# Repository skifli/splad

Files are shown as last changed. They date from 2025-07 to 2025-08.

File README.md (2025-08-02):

# Splad

- [Splad](#splad)
  - [Project Structure](#project-structure)
  - [Journal](#journal)
  - [PCB](#pcb)
    - [Schematic](#schematic)
    - [PCB Design \[Left\]](#pcb-design-left)
    - [PCB Design \[Right\]](#pcb-design-right)
  - [BOM](#bom)
  - [Software](#software)

| Cover | Exploded View (ish) |
| --- | --- |
| cover photo | exploded view photo |

A 48 key split ergonomic keyboard, with a screen and trackpad, created only using KiCad and Fusion 360 (no fancy tools like Ergogen, etc teeheehee - except for rending in Blender of course). The case is again in two sections, which join together via 8 magnets.

I made this project because my current keyboard is too loud for my workspace, and as well as that I wanted to try a new keyboard layout in my longer holiday post-GCSEs, so I decided to also design a split keyboard to more easily accomodate the new layout. As well as this, it is much more compact as I don't need to carry a separate keyboard and mouse. Even though my current keyboard is a membrane one its still noisy, especially because the keycaps slide against the case when moving down - something I prevented in my design, to reduce the noise.

## Project Structure

> [!IMPORTANT]\
> Only includes files / folders relevant to admin that would benefit from explanation.

```
└── 📁hackpad
    └── 📁production
        └── ... # Contains all Gerber ZIPs, case `.step` files, and also the .f3z project from Fusion 360 itself. The `plate-left.dxf` is the only DXF for the plate, as it was mirrored in KiCad, for the `plate-right.zip` - saves time.
    └── 📁firmware
        ├── ... # Contains the ZMK firmware
    ├── JOURNAL.md # The journal of the design process
    └── README.md # This file
```

## Journal

The [journal](JOURNAL.md) contains each day's work, logged, with the aid of images. Total time is at the top and each day has its time logged. There is also a Table of Contents for easy navigation :).

> [!WARNING]\
> Its unfinished, DM in the Slack if you're not Cyao to explain why - if you're Cyao you know why.

> [!NOTE]\
> Total time spent: **43h**

## PCB

Fully checked with DRC / ERC - no errors.

### Schematic

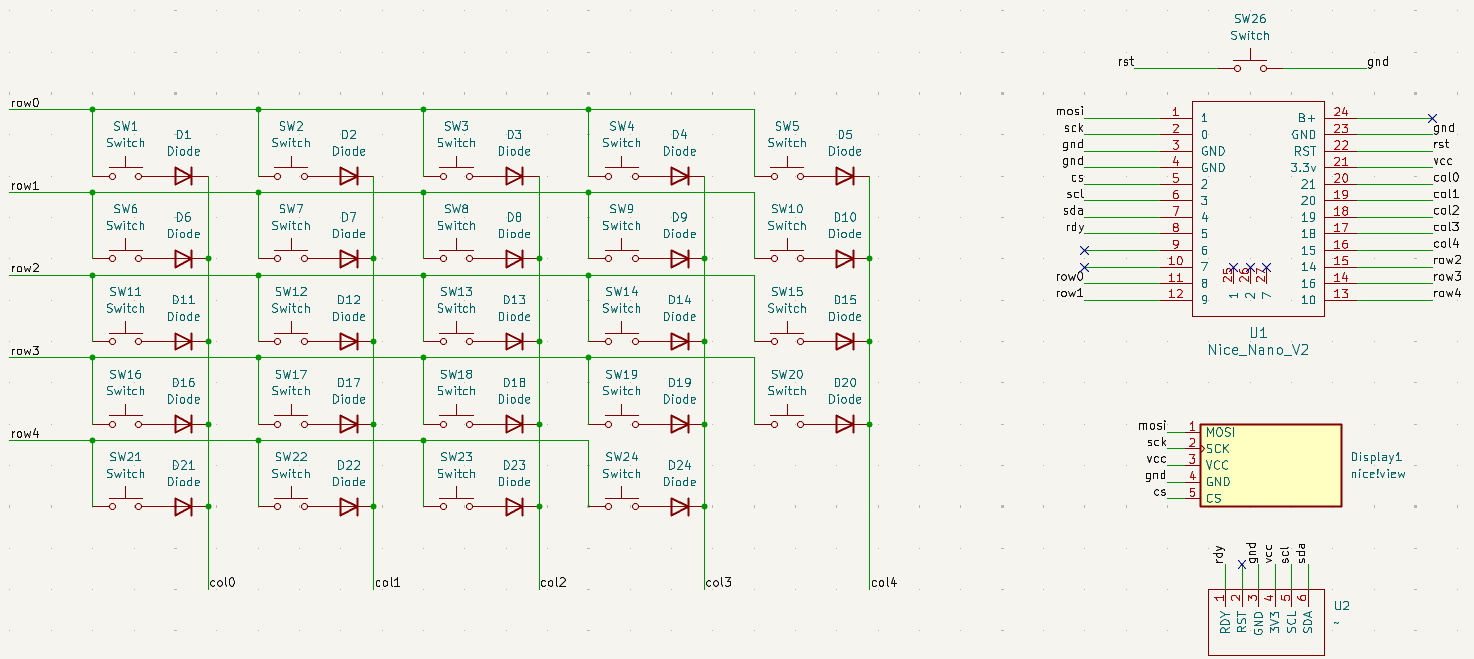
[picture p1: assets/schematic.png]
kciad schematic


### PCB Design [Left]

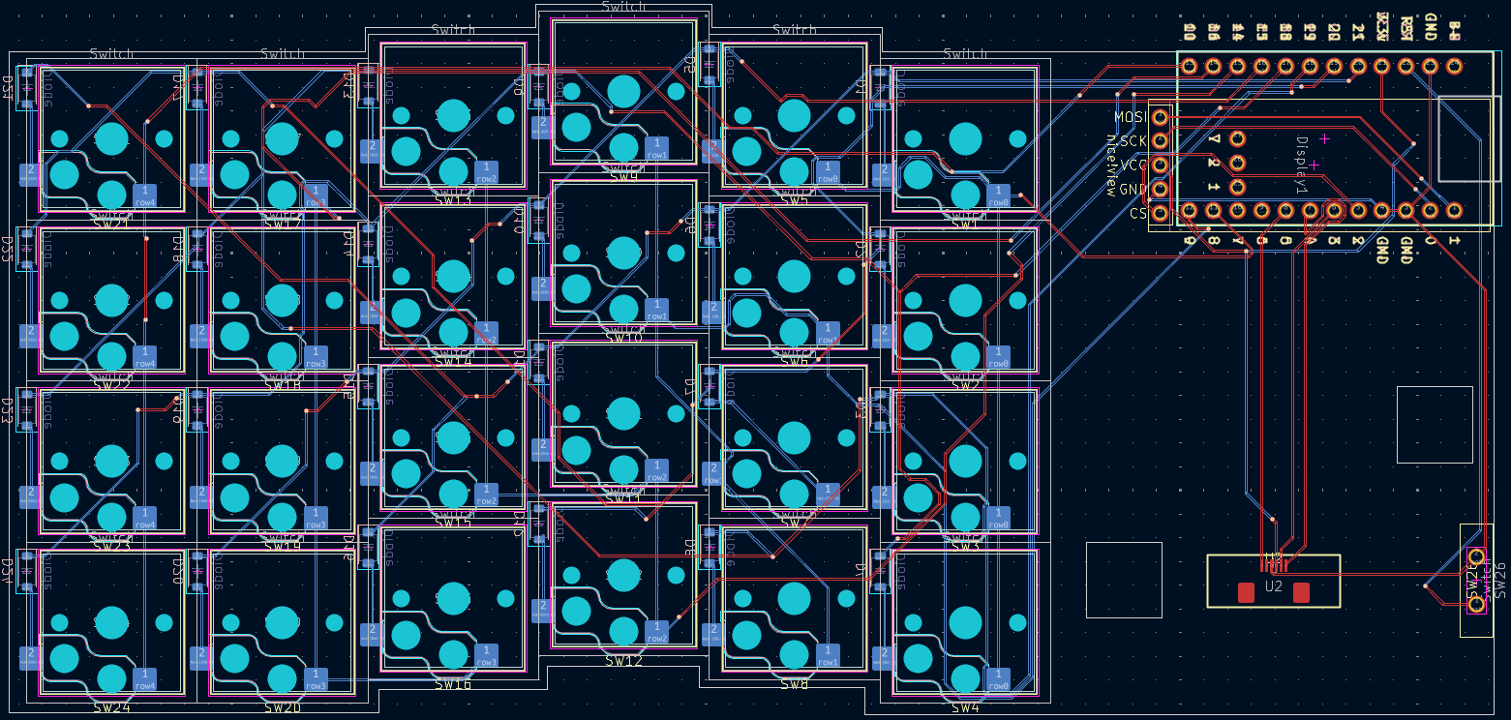
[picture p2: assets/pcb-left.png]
kiad pcb left


### PCB Design [Right]

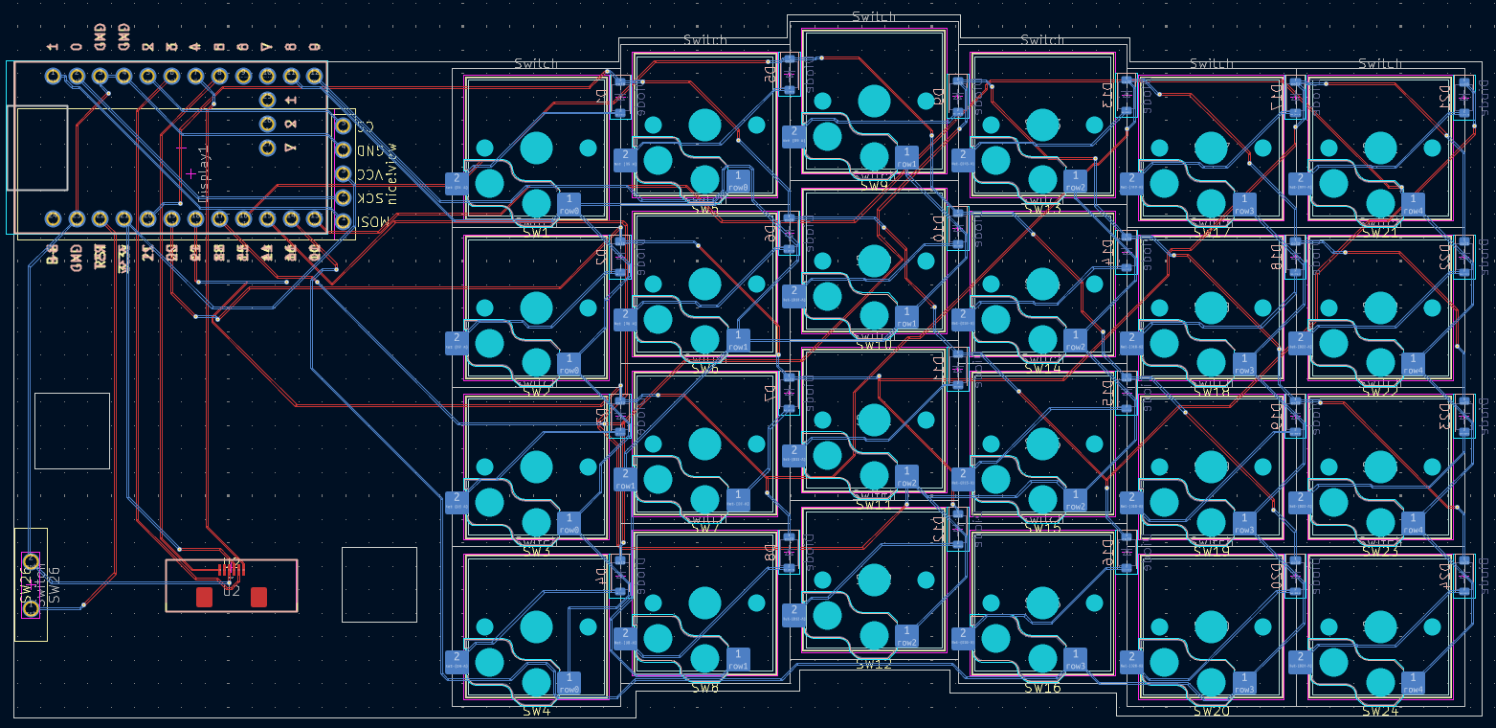
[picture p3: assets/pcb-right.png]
kicad pcb right


## BOM

$207.83

<details closed>
<summary>Click to open</summary>

| Component | Description | Notes | Quantity | Price | Shipping | Provider | Link |
| --- | --- | --- | --- | --- | --- | --- | --- |
| Headers | | For screen because it doesnt specify coming with some and I am taking zilch chances | 1 | £1.14 | | AliExpress | [Link](https://www.aliexpress.com/item/4000988113226.html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) |
| JST PH 2.00mm | PH 2.00mm | To connect the buttons to the PCB | 1 | £2.25 | | | [Link](https://www.aliexpress.com/item/1005007691949301.html) |
| Momentary Push Button | Red 5PCS | The actual button | 1 | £3.23 | | | [Link](https://www.aliexpress.com/item/1005008498887267.html) |
| Heat Shrink Tube | 164pcs / Mixed size  | To cover around the joint for the switch to power on / off the board | 1 | £1.28 | | | [Link](https://www.aliexpress.com/item/1005008146302901.html) |
| Slide Switch | k014a004-G3 | Switching it up here, eh? Lol ok thats enough bad jokes for a day ;-;. To switch on / off the board. | 1 | £0.77 | | | [Link](https://www.aliexpress.com/item/1005008904067609.html) |
| nice!nano v2 | But cheaaaper | We luv AliExpress | 2 | £3.00 | | | [Link](https://www.aliexpress.com/item/1005007383270623.html) |
| nice!view | But cheapy | Compatible screen (without headers) | 2 | £22.69 | | | [Link](https://www.aliexpress.com/item/1005008115497843.html) |
| Micro JST | Male 5 Pcs 100mm | [Adafruit Info](https://learn.adafruit.com/on-slash-off-switches/overview) | 1 | £0.32 | £2.03 | | [Link](https://www.aliexpress.com/item/1005008864177105.html) |
| Micro JST | Female 5 Pcs 100mm | [Adafruit Info](https://learn.adafruit.com/on-slash-off-switches/overview) | 1 | £0.48 | £2.03 | | [Link](https://www.aliexpress.com/item/1005008864177105.html) |
| Push Button | 6x6x6mm | For the reset function | 1 | £0.74 | £2.24 | | [Link](https://www.aliexpress.com/item/4001224103835.html) |
| "Supah Powerful" Disc Magnet | 4x3mm 50PCS | To hold the case together | 1 | £2.27 | | | [Link](https://www.aliexpress.com/item/1005009094333864.html) |
| Choc Keycaps v1 | 50 White Transparent | | 1 | £21.99 | | | [Link](https://www.aliexpress.com/item/1005009094333864.html) |
| Screws | | | 1 | £4.25 | | | [Link](https://www.aliexpress.com/item/1005007159750547.html) |
| 1N4148W SOD-123 Diodes | 100pcs | | 1 | £0.89 | | | [Link](https://www.aliexpress.com/item/4000685043735.html) |
| Self Adhesive Rubber Bumpers | 100pcs 5mmx2mm | For PCB and bottom of the case | 1 | £1.69 | | | [Link](https://www.aliexpress.com/item/1005004068119765.html) |
| Kalih Hot Swap Socket | 50pcs | For switches | 1 | £4.89 | | | [Link](https://www.aliexpress.com/item/1005003575767699.html) |
| FPC Connector | 6p/10pcs | To solder to the PCB, to connect to the TPS43 | 1 | £0.74 | | | [Link](https://www.aliexpress.com/item/1005009196851411.html) |
| FPC Ribbon | | The actual ribbon to connect to the TPS43 | 2 | £3.02 | | | [Link](https://www.aliexpress.com/item/1005007078121242.html) |
| Kailh Choc Switches | Pink 50pcs | Quitest ones I can find that aren't atrociously priced lol | 1 | £18.39 | | | [Link](https://www.aliexpress.com/item/1005008883418065.html) |
| **Total (AliExpress)** | | | | **£92.62**  | Included | | |
| 150mAh 3.7V LiPo Battery | | Couldn't find earlier AliExpress ones. 150mAh, JST, right specs. | 2 | £9.00 | £3.90 | PiHut | [Link](https://thepihut.com/products/150mah-3-7v-lipo-battery?variant=42388690993347) |
| **Total (PiHut)** | | | | **£12.90**  | | | |
| TPS43 | | Trackpad | 2 | £7.90 | £12.00 | | |
| **Total (Mouser)** | | | | **£19.90**  | | | |
| PCB Left | | | 1 | £6.42 | £7.34 | JLCPCB | |
| PCB Right | | | 1 | £6.42 | | | |
| Plate Left | | | 1 | £5.44 | | | |
| Plate Right | | | 1 | £5.44 | | | |
| **Total (JLCPCB)** | | | | **£31.07**  | Included | | |
| **TOTAL** | | | | **£156.49** | | | |

</details>

## Software

Will be _mostly_ added once the physical components are received and assembled, as I don't want to start writing code and then find out it doesn't work because I accidentally used libraries for different components, or something similar to that.

I have added some code in the [`/firmware`](firmware) directory though.

---
<sub>Thanks to [Hackclub](https://hackclub.com) for such an amazing opportunity - this project was made by [@skifli](https://github.com/skifli) with 🩷, under the [MIT License](LICENSE).</sub>

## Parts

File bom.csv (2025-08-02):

Component | Description | Notes | Quantity | Price | Shipping | Provider | Link
Headers |  | For screen because it doesnt specify coming with some and I am taking zilch chances | 1 | £1.14 |  | AliExpress | https://www.aliexpress.com/item/4000988113226.html?mp=1
JST PH 2.00mm | PH 2.00mm | To connect the buttons to the PCB | 1 | £2.25 |  |  | https://www.aliexpress.com/item/1005007691949301.html?mp=1
Momentary Push Button | Red 5PCS | The actual button | 1 | £3.23 |  |  | https://www.aliexpress.com/item/1005008498887267.html?mp=1
Heat Shrink Tube | 164pcs / Mixed size | To cover around the joint for the switch to power on / off the board | 1 | £1.28 |  |  | https://www.aliexpress.com/item/1005008146302901.html?mp=1
Slide Switch | k014a004-G3 | Switching it up here, eh? Lol ok thats enough bad jokes for a day ;-;. To switch on / off the board. | 1 | £0.77 |  |  | https://www.aliexpress.com/item/1005008904067609.html?mp=1
nice!nano v2 | But cheaaaper | We luv AliExpress | 2 | £3.00 |  |  | https://www.aliexpress.com/item/1005007383270623.html?mp=1
nice!view | But cheapy | Compatible screen (without headers) | 2 | £22.69 |  |  | https://www.aliexpress.com/item/1005008115497843.html?mp=1
Micro JST | Male 5 Pcs 100mm | https://learn.adafruit.com/on-slash-off-switches/overview | 1 | £0.32 | £2.03 |  | https://www.aliexpress.com/item/1005008864177105.html?mp=1
Micro JST | Female 5 Pcs 100mm | https://learn.adafruit.com/on-slash-off-switches/overview | 1 | £0.48 | £2.03 |  | https://www.aliexpress.com/item/1005008864177105.html?mp=1
Push Button | 6x6x6mm | For the reset function | 1 | £0.74 | £2.24 |  | https://www.aliexpress.com/item/4001224103835.html?mp=1
"Supah Powerful" Disc Magnet | 4x3mm 50PCS | To hold the case together | 1 | £2.27 |  |  | https://www.aliexpress.com/item/1005009094333864.html?mp=1
Choc Keycaps v1 | 50 White Transparent |  | 1 | £21.99 |  |  | https://www.aliexpress.com/item/1005009094333864.html?mp=1
Screws |  |  | 1 | £4.25 |  |  | https://www.aliexpress.com/item/1005007159750547.html?mp=1
1N4148W SOD-123 Diodes | 100pcs |  | 1 | £0.89 |  |  | https://www.aliexpress.com/item/4000685043735.html?mp=1
Self Adhesive Rubber Bumpers | 100pcs 5mmx2mm | For PCB and bottom of the case | 1 | £1.69 |  |  | https://www.aliexpress.com/item/1005004068119765.html?mp=1
Kalih Hot Swap Socket | 50pcs | For switches | 1 | £4.89 |  |  | https://www.aliexpress.com/item/1005003575767699.html?mp=1
FPC Connector | 6p/10pcs | To solder to the PCB, to connect to the TPS43 | 1 | £0.74 |  |  | https://www.aliexpress.com/item/1005009196851411.html?mp=1
FPC Ribbon |  | The actual ribbon to connect to the TPS43 | 2 | £3.02 |  |  | https://www.aliexpress.com/item/1005007078121242.html?mp=1
Kailh Choc Switches | Pink 50pcs | Quitest ones I can find that aren't atrociously priced lol | 1 | £18.39 |  |  | https://www.aliexpress.com/item/1005008883418065.html?mp=1
Total (AliExpress) |  |  |  | £92.62 | Included on ze left!
150mAh 3.7V LiPo Battery |  | I promise, I could find NO batteries on AliExpress that didn't ship in September / around August 30th ;-; (thats still 150mAh, JST connector, right voltage, etc). | 2 | £9 | £3.90 | PiHut | https://thepihut.com/products/150mah-3-7v-lipo-battery?variant=42388690993347
Total (PiHut) |  |  |  | £12.90
TPS43 |  | Trackpad | 2 | £7.90 | £12
Total (Mouser) |  |  |  | £19.90
PCB Left |  |  | 1 | £6.42 | £7.34 | JLCPCB
PCB Right |  |  | 1 | £6.42
Plate Left |  |  | 1 | £5.44
Plate Right |  |  | 1 | £5.44
 |  |  |  | £31.07 | Included on ze left!
TOTAL |  |  |  | £156.49

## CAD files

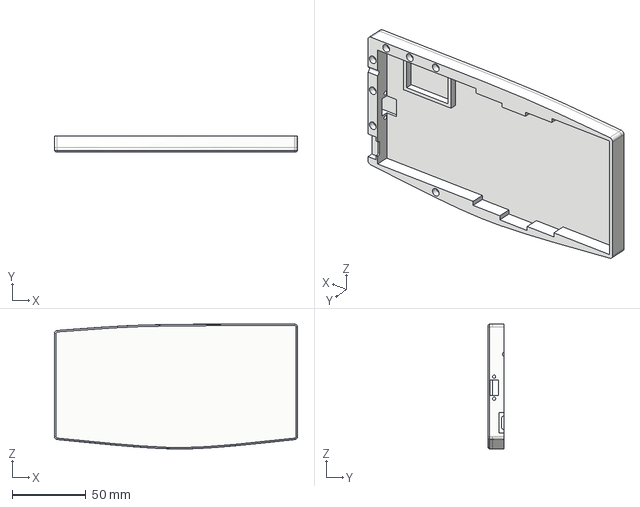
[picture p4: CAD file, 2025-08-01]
production/case_bottom_left.step
165.1 x 10.9 x 84.9 mm

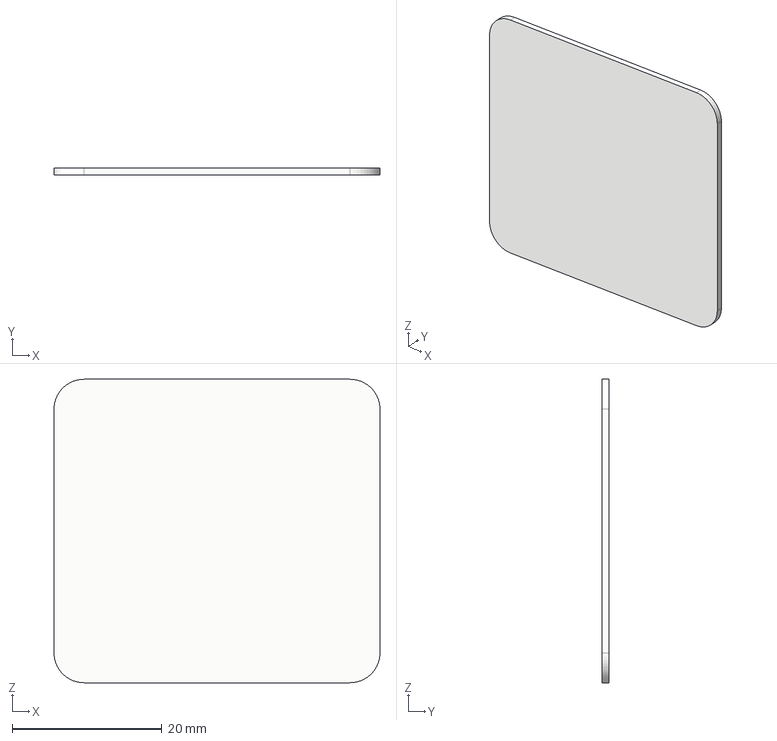
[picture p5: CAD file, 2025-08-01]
production/trackpad_cover_ambidextrous.step
43.5 x 1 x 40.5 mm

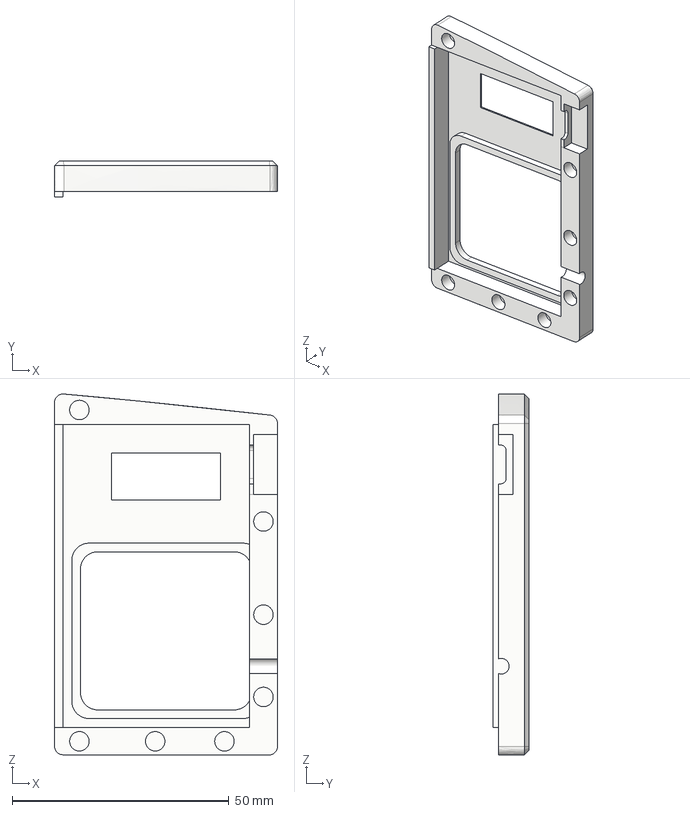
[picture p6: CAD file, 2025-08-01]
production/case_top_right.step
51.5 x 8.20 x 83.4 mm

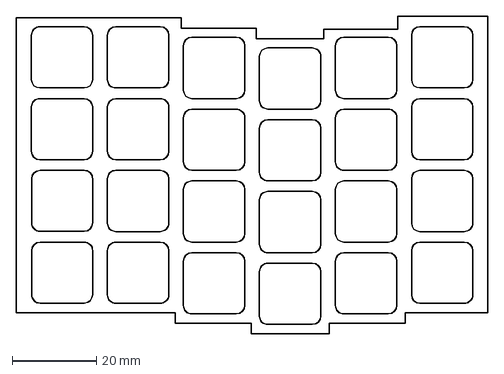
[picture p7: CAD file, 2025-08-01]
production/plate-left.dxf
111.6 x 75.2 mm

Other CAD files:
production/case_top_left.step
production/case_bottom_right.step

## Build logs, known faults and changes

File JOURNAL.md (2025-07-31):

---
title: "Splad"
author: "skifli"
description: "A split ergonomic keyboard with a trackball and screen(s)"
created_at: "2025-07-21"
---

# Journal

- [Journal](#journal)
  - [21/07/2025](#21072025)
  - [22/07/2025](#22072025)
  - [23/07/2025](#23072025)

> [!NOTE]\
> Total time spent: **17h**

## 21/07/2025

Researching components, I'll probably go with the Raspberry Pi Pico 2WH.

> [!NOTE]\
> Total time spent: **2h**

## 22/07/2025

Nice OLED - https://www.aliexpress.com/item/1005005906852549.html
Trackball Breakout - https://shop.pimoroni.com/products/trackball-breakout?variant=27672765038675

Ok so on each side:
* 5 columns on the main part, staggered. In 3 rows, to make the main section.
* An extra column on the outer side (for extra stuff - the alphabet will cover the main part).
* Then a few keys underneath and out towards the screen for thumb modifiers etc (shift, other layers, etc).

Did a reddit post: https://www.reddit.com/r/KeyboardLayouts/comments/1m6a7mj/layouts_for_those_without_a_left_ring_finger/

Ok so each side will have 18 keys + 3 modifier keys = 21 keys, 42 in total. Thats a 5x5 matrix so 10 GPIO pins needed.

I have decided to use the Raspberry Pi Pico 2 W.

Nevermind, its later and back to the nice! nano v2 as it has LiPo charging built in, a USB C port, Bluetooth, etc.

Going to use this display: https://www.aliexpress.com/item/1005006141235306.html
And this trackball (I will have to create a schematic etc for it ;-;): https://www.aliexpress.com/item/1005009386877838.html

Set up a basic key matrix:

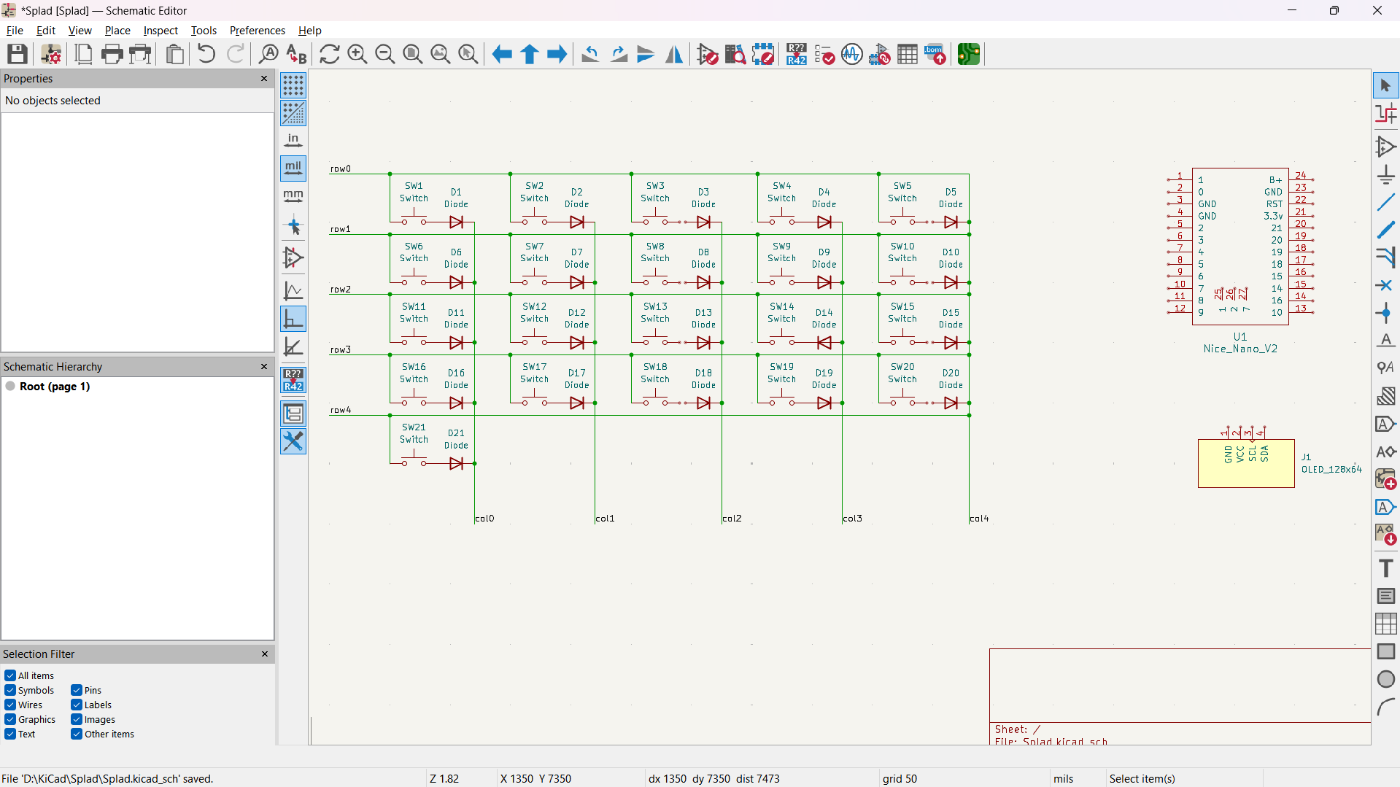
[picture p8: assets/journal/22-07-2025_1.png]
basic key matrix in kicad


> [!NOTE]\
> Total time spent: **5h**

## 23/07/2025

Finished symbol (I numbered them after dw lol):

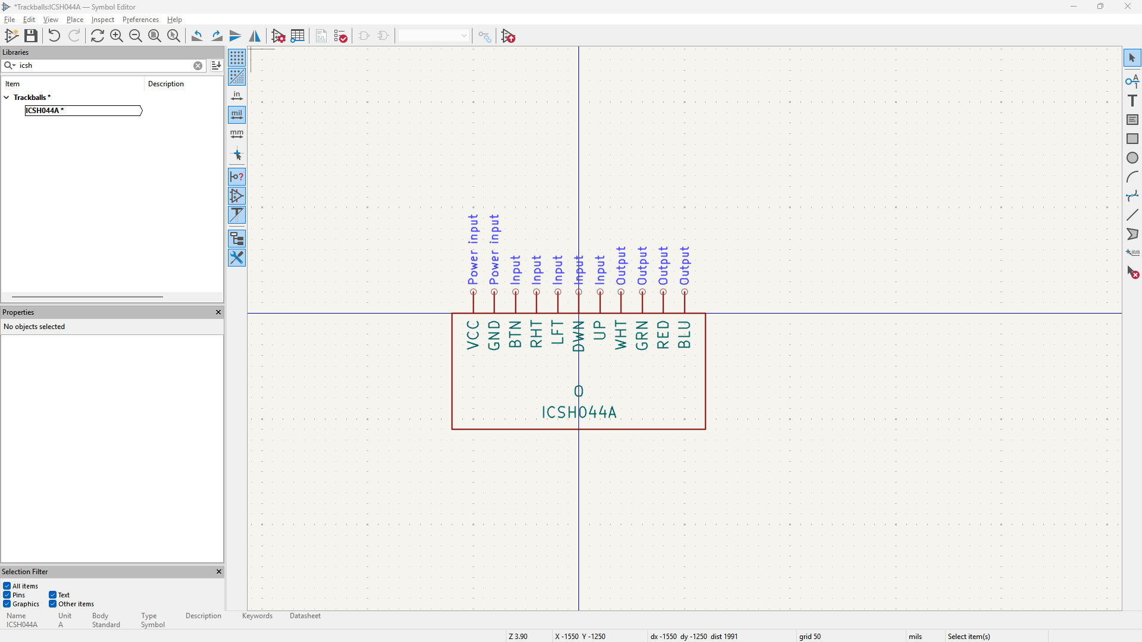
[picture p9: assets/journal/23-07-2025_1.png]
finished symbol in kicad for the ICSH044A


I have decided not to wire to the lighting pins because I don't want the trackball to light up.

Found this Sparkfun one which has Eagle files I'll convert into KiCad for the footprint: https://github.com/sparkfun/Blackberry_Trackballer_Breakout/blob/master/Hardware/SparkFun_Blackberry_Trackballer_Breakout.sch. Its got the same pins just slightly different dimensions

Pretty sure this is good - I had to change a bunch of dimensions and stuff but it's fine, and also swap the labelling of the pins:

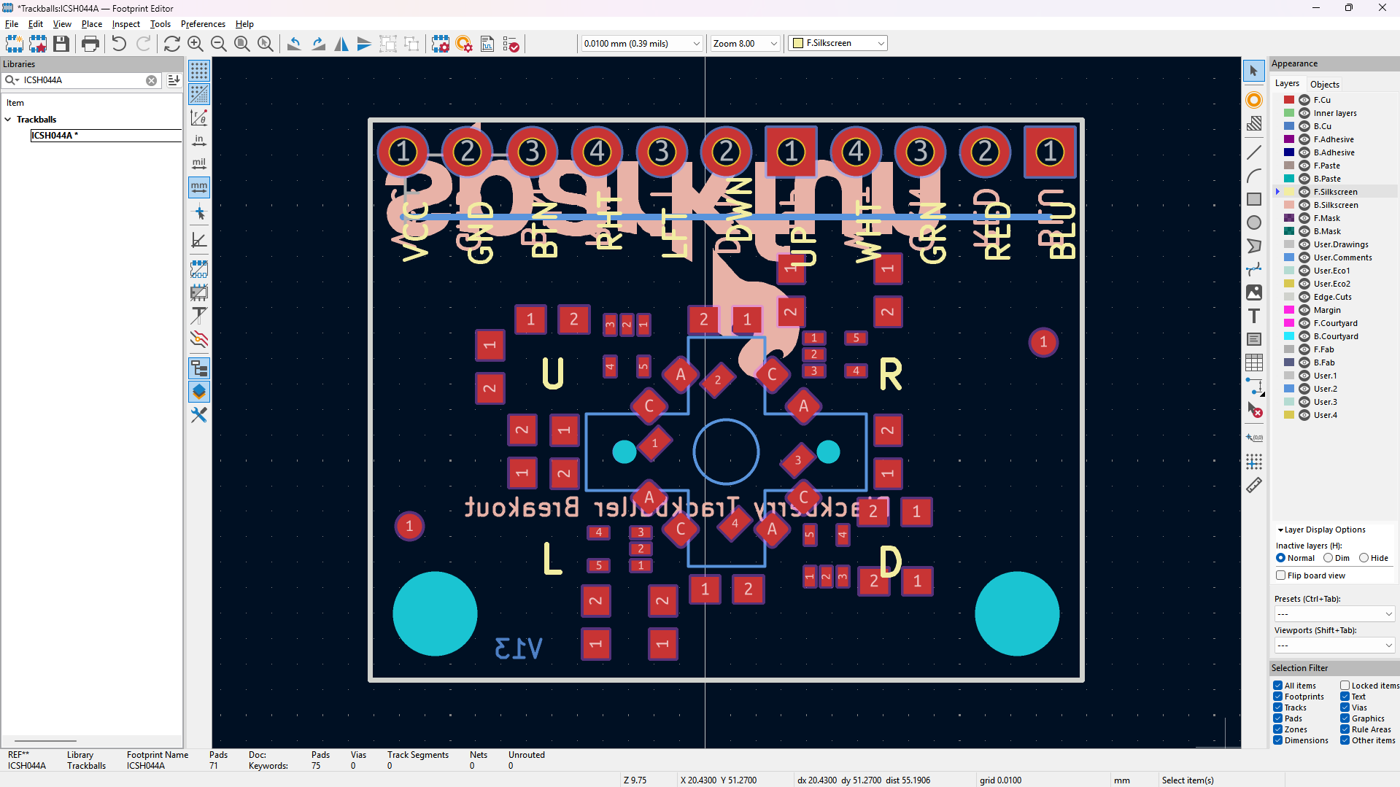
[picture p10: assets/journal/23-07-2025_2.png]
finished footprint for the ICSH044A


I have decided to use the nice! view (or compatible from AliExpress) due to a MUCH longer battery life (it reflects light, OLEDs emit it - source, Reddit, the best source ofc). Srs tho Reddit is so useful.

Finished the schematic (special mention to the Electrical Rules Checker which saved me a lot of heartaches later down lol):

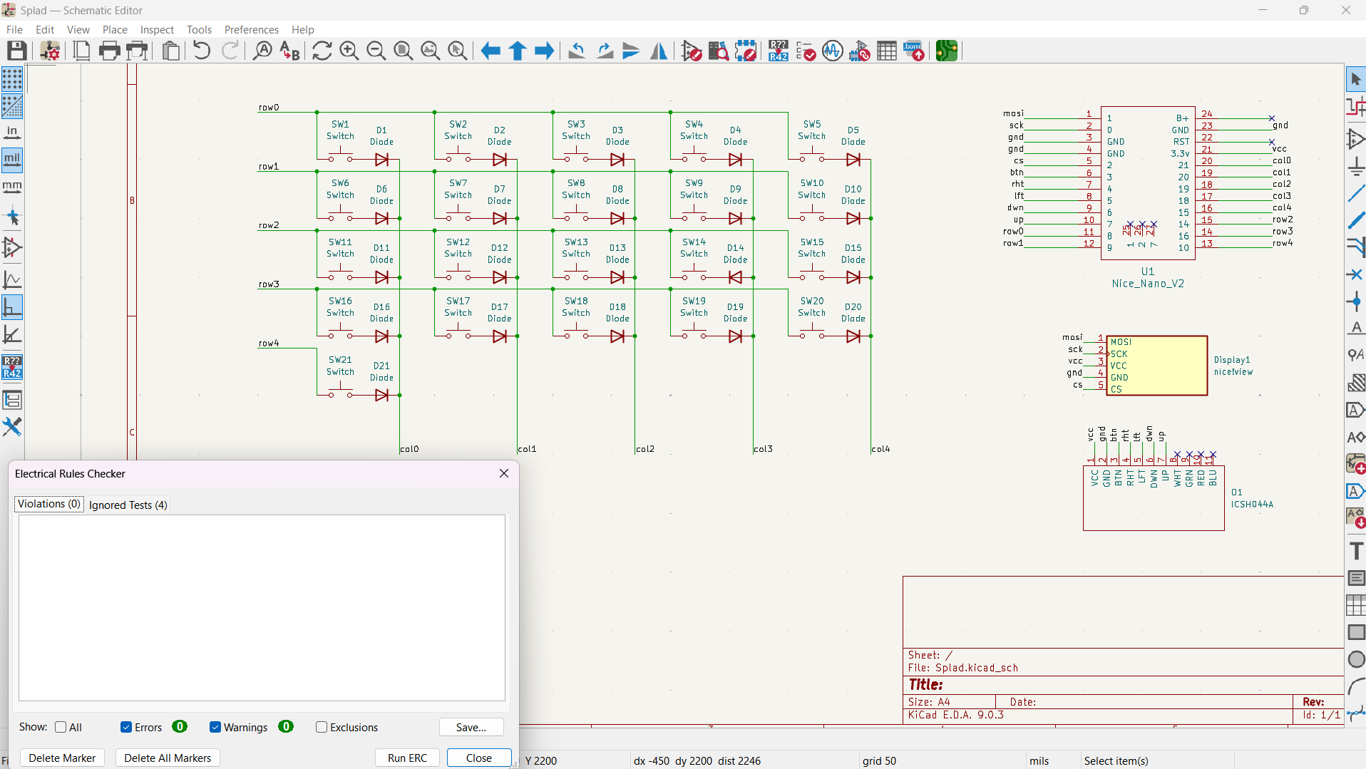
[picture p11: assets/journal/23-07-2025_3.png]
finished schematic


I have decided to add a button to RST as well.

Started by importing stuff into the PCB editor.

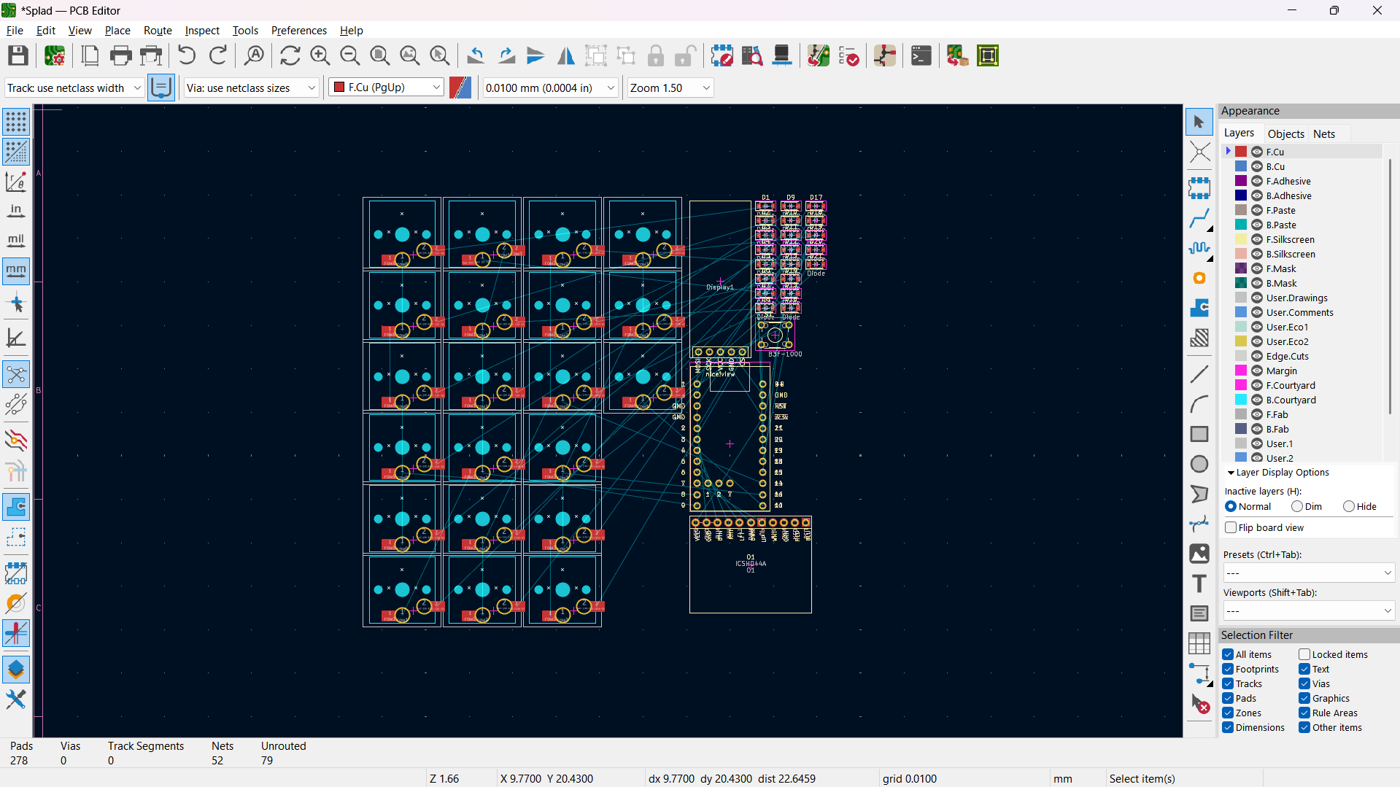
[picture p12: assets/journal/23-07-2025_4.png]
starting pcb import


Useful for column stagger: https://flatfootfox.com/ergogen-part1-units-points/

Useful thing I found about connecting a battery:

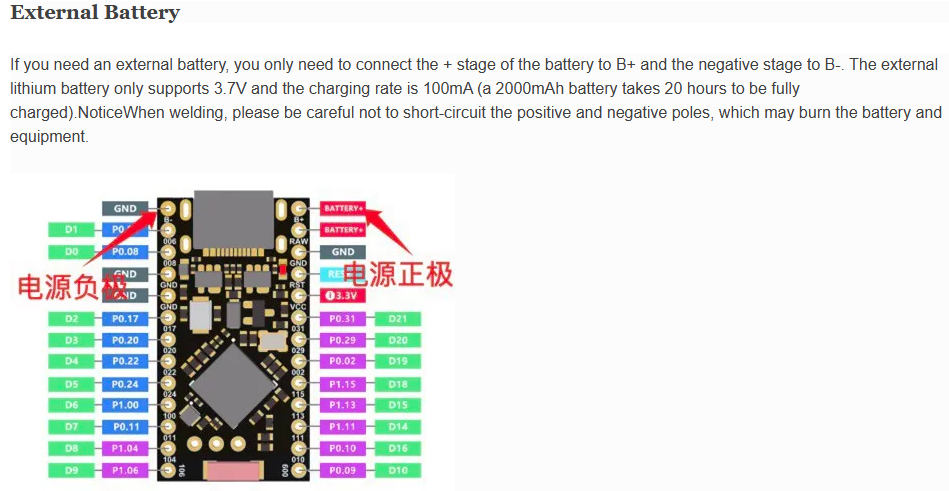
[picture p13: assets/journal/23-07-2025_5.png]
aliexpress documentation on attaching a battery to the nice nano v2


0.25mm for outside line

Not done routing yet but main shape done:
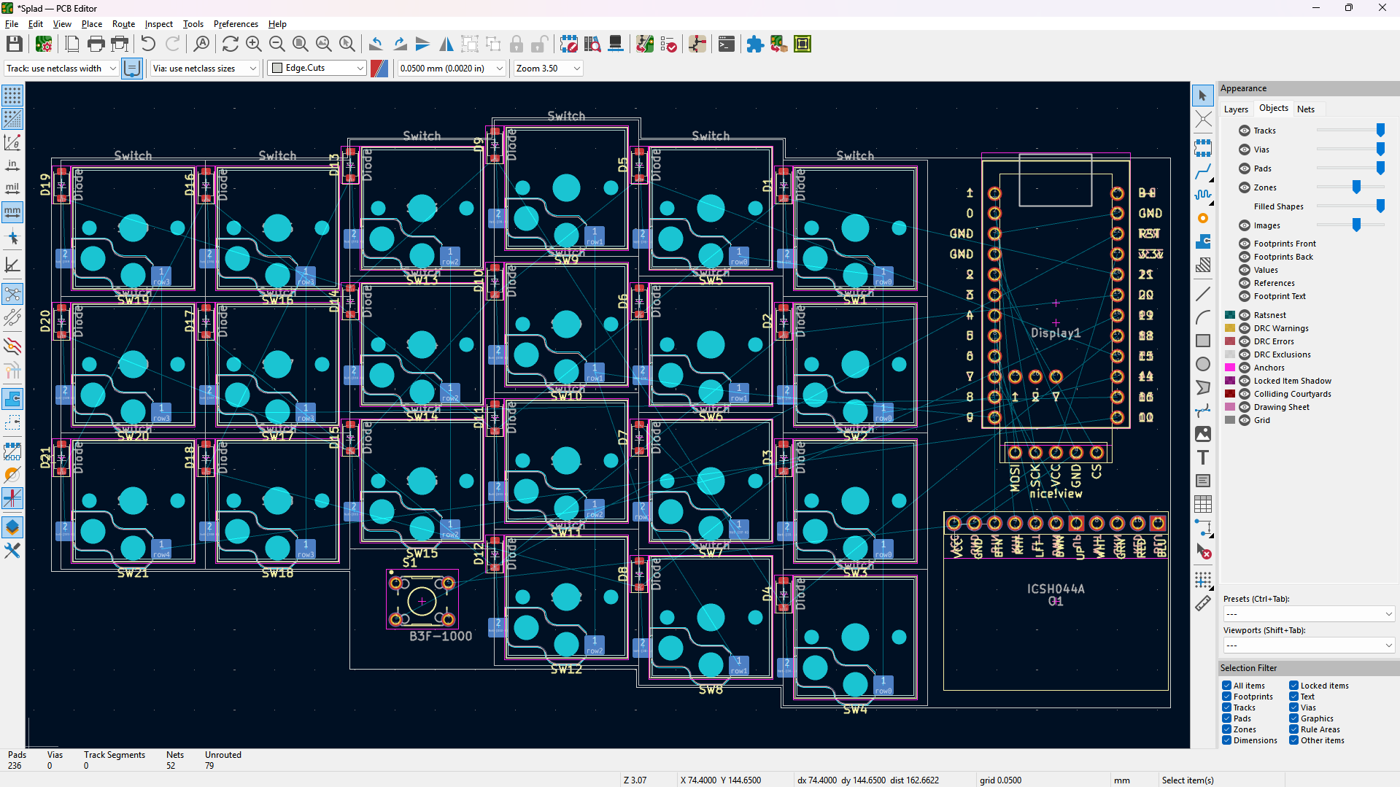
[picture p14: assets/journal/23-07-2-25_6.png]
layed out pcb without routing

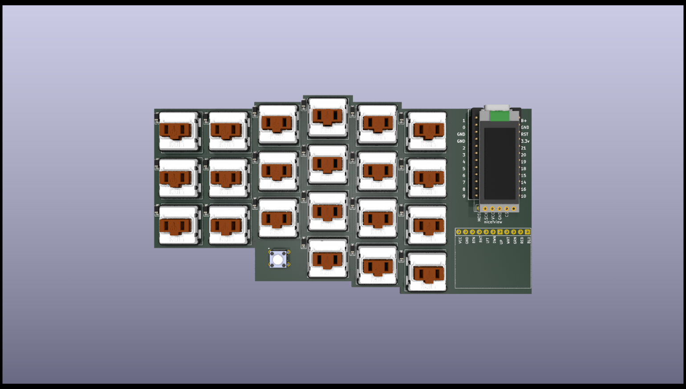
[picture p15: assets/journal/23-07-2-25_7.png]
pcb render without routing done


For now I'll work on the case as I might have to move components depending on how the case goes which would mean rerouting if I route now.

> [!NOTE]\
> Total time spent: **10h**

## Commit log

2025-07-31 feat: upload design part 1
    [Splad.kicad_pcb, Splad.kicad_sch, bom.csv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]
2025-07-31 feat: update design part 2
    [Splad.kicad_pcb, Splad.kicad_sch, bom.csv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]
2025-07-31 feat: update `README.md`
    [bom.csv]
2025-07-31 fix: update bom
    [bom.csv]
2025-08-01 feat: reduce BOM and beautify the layout
    [Splad.kicad_pcb, Splad.kicad_sch, bom.csv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]
2025-08-01 fix: wrong schematic `README.md` link
2025-08-02 fix: update `bom.csv` to more
    [bom.csv]
2025-08-02 fix: forgot to update `README.md` bom
